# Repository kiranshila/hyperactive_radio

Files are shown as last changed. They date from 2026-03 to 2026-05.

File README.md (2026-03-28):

# Hyperactive//2026 Radio

Experimental real-time, long-range, high-quality, wireless digital audio for Hyperactive 2026.

## Audio quality

| Parameter | Value |
|---|---|
| Codec | Opus (fixed-point) |
| Bitrate | 64 kbps |
| Channels | Stereo |
| Sample rate | 48 kHz |
| Frame size | 20 ms |
| Encoder complexity | 5 / 10 |
| ADC | PCM1808 (24-bit I2S) |

64 kbps stereo Opus at 48 kHz should be transparent for most program material — comparable to a good 128 kbps MP3, but with lower latency and better behaviour at the edges of the bitrate.
The fixed-point build removes float entirely; no performance penalty on Cortex-M33 which has a hardware FPU but where the float Opus path was benchmarked to be slower than fixed-point.

End-to-end latency is approximately one frame (20 ms) of algorithmic delay plus radio airtime (~1.6 ms at 100 kbps for a 160-byte packet) plus any playout buffer on the receiver.

## Radio

| Parameter | Value |
|---|---|
| Radio IC | SX1276 |
| Band | 915 MHz (US ISM) |
| Modulation | GFSK |
| Air rate | 100 kbps |
| TX power | +20 dBm (100 mW) |
| Target range | ~300 m / ~1000 ft mixed indoor/outdoor |
| Link margin | ~18 dB at 100 kbps GFSK |

### Regulatory (FCC Part 15.247)

No frequency hopping required. Part 15.247 has two compliance paths — FHSS is one, but **digital modulation** is the other: fixed frequency, up to +30 dBm EIRP, with two constraints:

- **6 dB bandwidth ≥ 500 kHz** — requires high frequency deviation; at 100 kbps, ±200 kHz deviation gets you there (`BW_6dB ≈ 2 × f_dev + bit_rate`). Lower deviation (e.g. ±50 kHz) only yields ~200 kHz and does not qualify.
- **PSD ≤ 8 dBm in any 3 kHz band** — GFSK spectral peaks at ±f_dev must stay under this limit at the chosen TX power.

The exact deviation and power settings need to be verified against both constraints once the RF configuration is finalised. At +20 dBm with sufficiently high deviation the path is viable, but the numbers need to be checked.

### Packet structure

Each 20 ms Opus frame encodes to roughly 160 bytes at 64 kbps.
With ~10 bytes of framing (sequence number, network ID, CRC) the total packet is ~170 bytes, for an effective air rate of ~68 kbps — well within the 100 kbps channel.

## Performance

MCU runs at **270 MHz** (overclocked from the 150 MHz default; stable at stock 1.1 V).

Benchmarked on hardware against broadband LCG noise (worst case for Opus — no clear pitch, flat spectrum):

| Operation | Cycles (avg) | Time (avg) | Frame budget used |
|---|---|---|---|
| Opus encode, stereo, 64 kbps, 20 ms | 2,299,603 | 8.5 ms | **42.6%** |
| Opus decode, stereo, 64 kbps, 20 ms | 895,420 | 3.3 ms | **16.6%** |

Frame budget = 20 ms = 5,400,000 cycles at 270 MHz.

The encoder leaves 11.5 ms of headroom per frame for I2S DMA and SPI radio management.
The decoder uses only 16.6% of the frame, leaving ample margin for playout buffering and output DMA.

## Firmware architecture

Written in Rust (`no_std`, Embassy async runtime).

```
ha_radio/          # firmware binary (bench + main)
embedded-opus/     # safe Rust wrapper around libopus
opus-sys/          # raw FFI bindings; builds libopus via cc crate
```

`embedded-opus/build.rs` compiles a host-side C probe at build time to determine the exact encoder and decoder state sizes, so buffers are sized precisely without a runtime heap.

### Planned: dual-core pipeline

The encode headroom is comfortable at 270 MHz, but the dual-core split is still planned for clean separation of concerns once the ADC arrives:

- **Core 0** — I2S DMA capture, SX1276 SPI, radio management
- **Core 1** — Opus encode only

A pair of Embassy `Channel` queues (depth 2) connect the cores: PCM frames inbound, encoded packets outbound.

## Build

```sh
cargo build --release --bin ha_radio
cargo build --release --bin bench
```

Requires a Rust nightly toolchain and the `thumbv8m.main-none-eabihf` target (see `rust-toolchain.toml`).

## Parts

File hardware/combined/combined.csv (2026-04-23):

Reference | Qty | Value | MPN | LCSC
A1 | 1 | RaspberryPi_Pico |  | C41407547
C1,C3,C6,C8,C10,C12,C13,C14,C15,C17 | 10 | 10u
C2 | 1 | 22u
C4,C7,C9,C11,C18,C19,C20 | 7 | 100n
C21,C22,C27 | 3 | 1u
C23,C24,C25,C26 | 4 | 220p
FB1,FB6,FB7,FB8,FB9,FB10 | 6 | BLM18PG221SN1 | BLM18PG221SN1 | C80165
J1 | 1 | Barrel_Jack_MountingPin
J2 | 1 | Conn_01x03_Pin
J3,J7 | 2 | Conn_01x02
J4 | 1 | Conn_Coaxial |  | C496550
J8,J9 | 2 | AudioJack3_SwitchT | SJ-3524-SMT-TR | C20182907
Q1 | 1 | DMG2305UX |  | C150470
R1 | 1 | 100k
R2,R3,R4 | 3 | 4.7k
R7 | 1 | 22k
SW1 | 1 | RotaryEncoder_Switch_MP | EC11E18244A5 | C255515
U1 | 1 | LD1117S50TR_SOT223 |  | C347230
U2 | 1 | Ai-Thinker-Ra-01 |  | C503593
U3 | 1 | PCM3060 | PCM3060PWR | C2651841
U4 | 1 | SSD1306
U6 | 1 | PAM8406D | PAM8406DR | C86270
Y1 | 1 | SG-210STF | X1G0041710019 | C255992

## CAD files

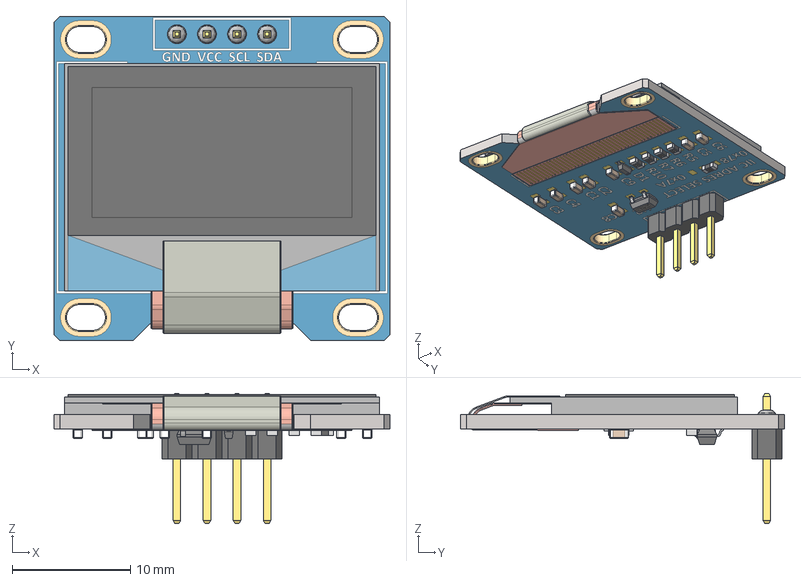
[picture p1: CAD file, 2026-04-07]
hardware/combined/Pantalla OLED 0.96'' 128x64.stp
28.4 x 27.4 x 11.0 mm
SOT-23_TOR
RES_CR16_MTK_1 x 4
RES_CR16_MTK
SOD323F_DIO

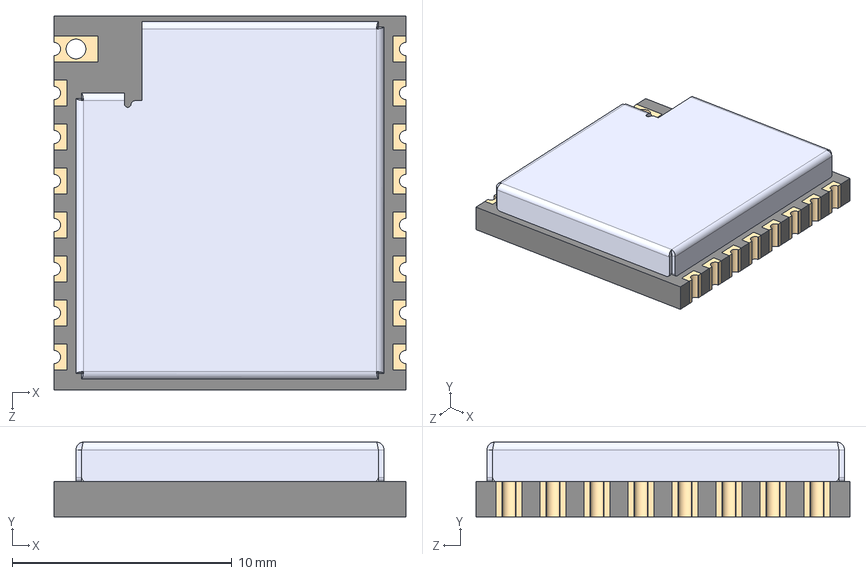
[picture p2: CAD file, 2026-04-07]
hardware/combined/RA-01H--3DModel-STEP-1.STEP
16.0 x 3.40 x 17.0 mm

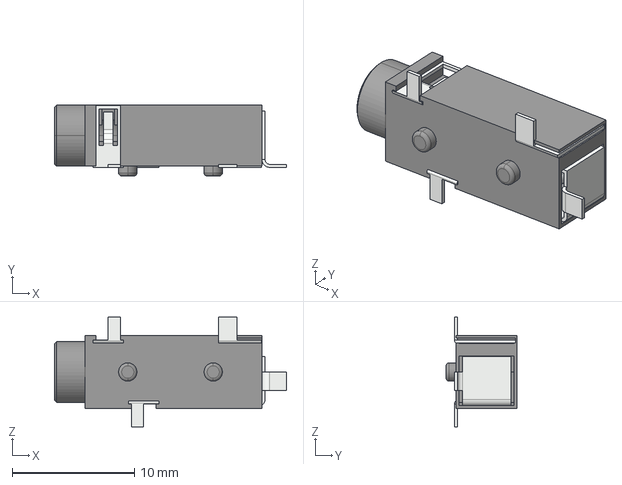
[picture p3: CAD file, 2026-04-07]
hardware/combined/CUI_SJ-3524-SMT-TR.STEP
19.0 x 5.80 x 9.00 mm

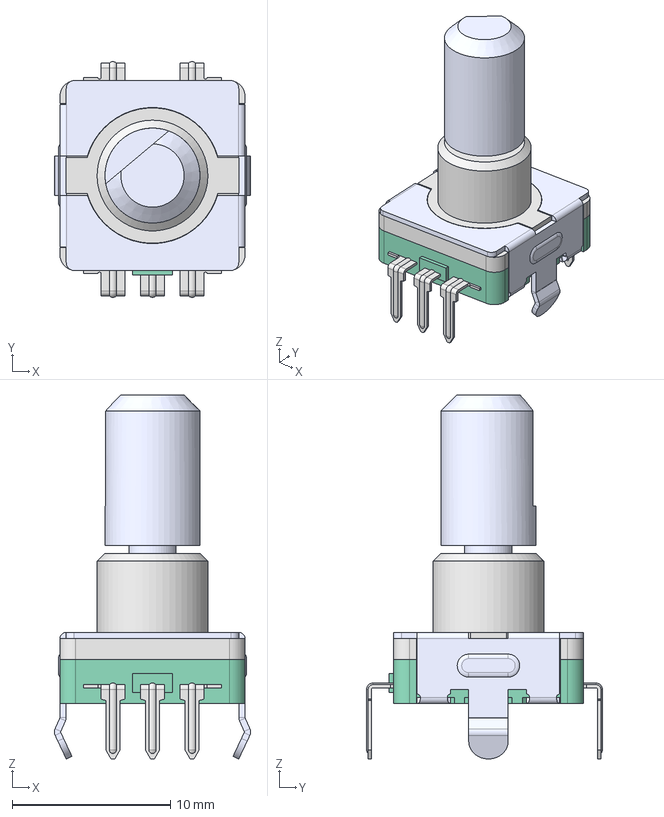
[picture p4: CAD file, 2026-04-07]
hardware/combined/EC11-THT-15F-green.step
12.4 x 14.9 x 23.0 mm
Lb5
15F
EC11-Housing-THT

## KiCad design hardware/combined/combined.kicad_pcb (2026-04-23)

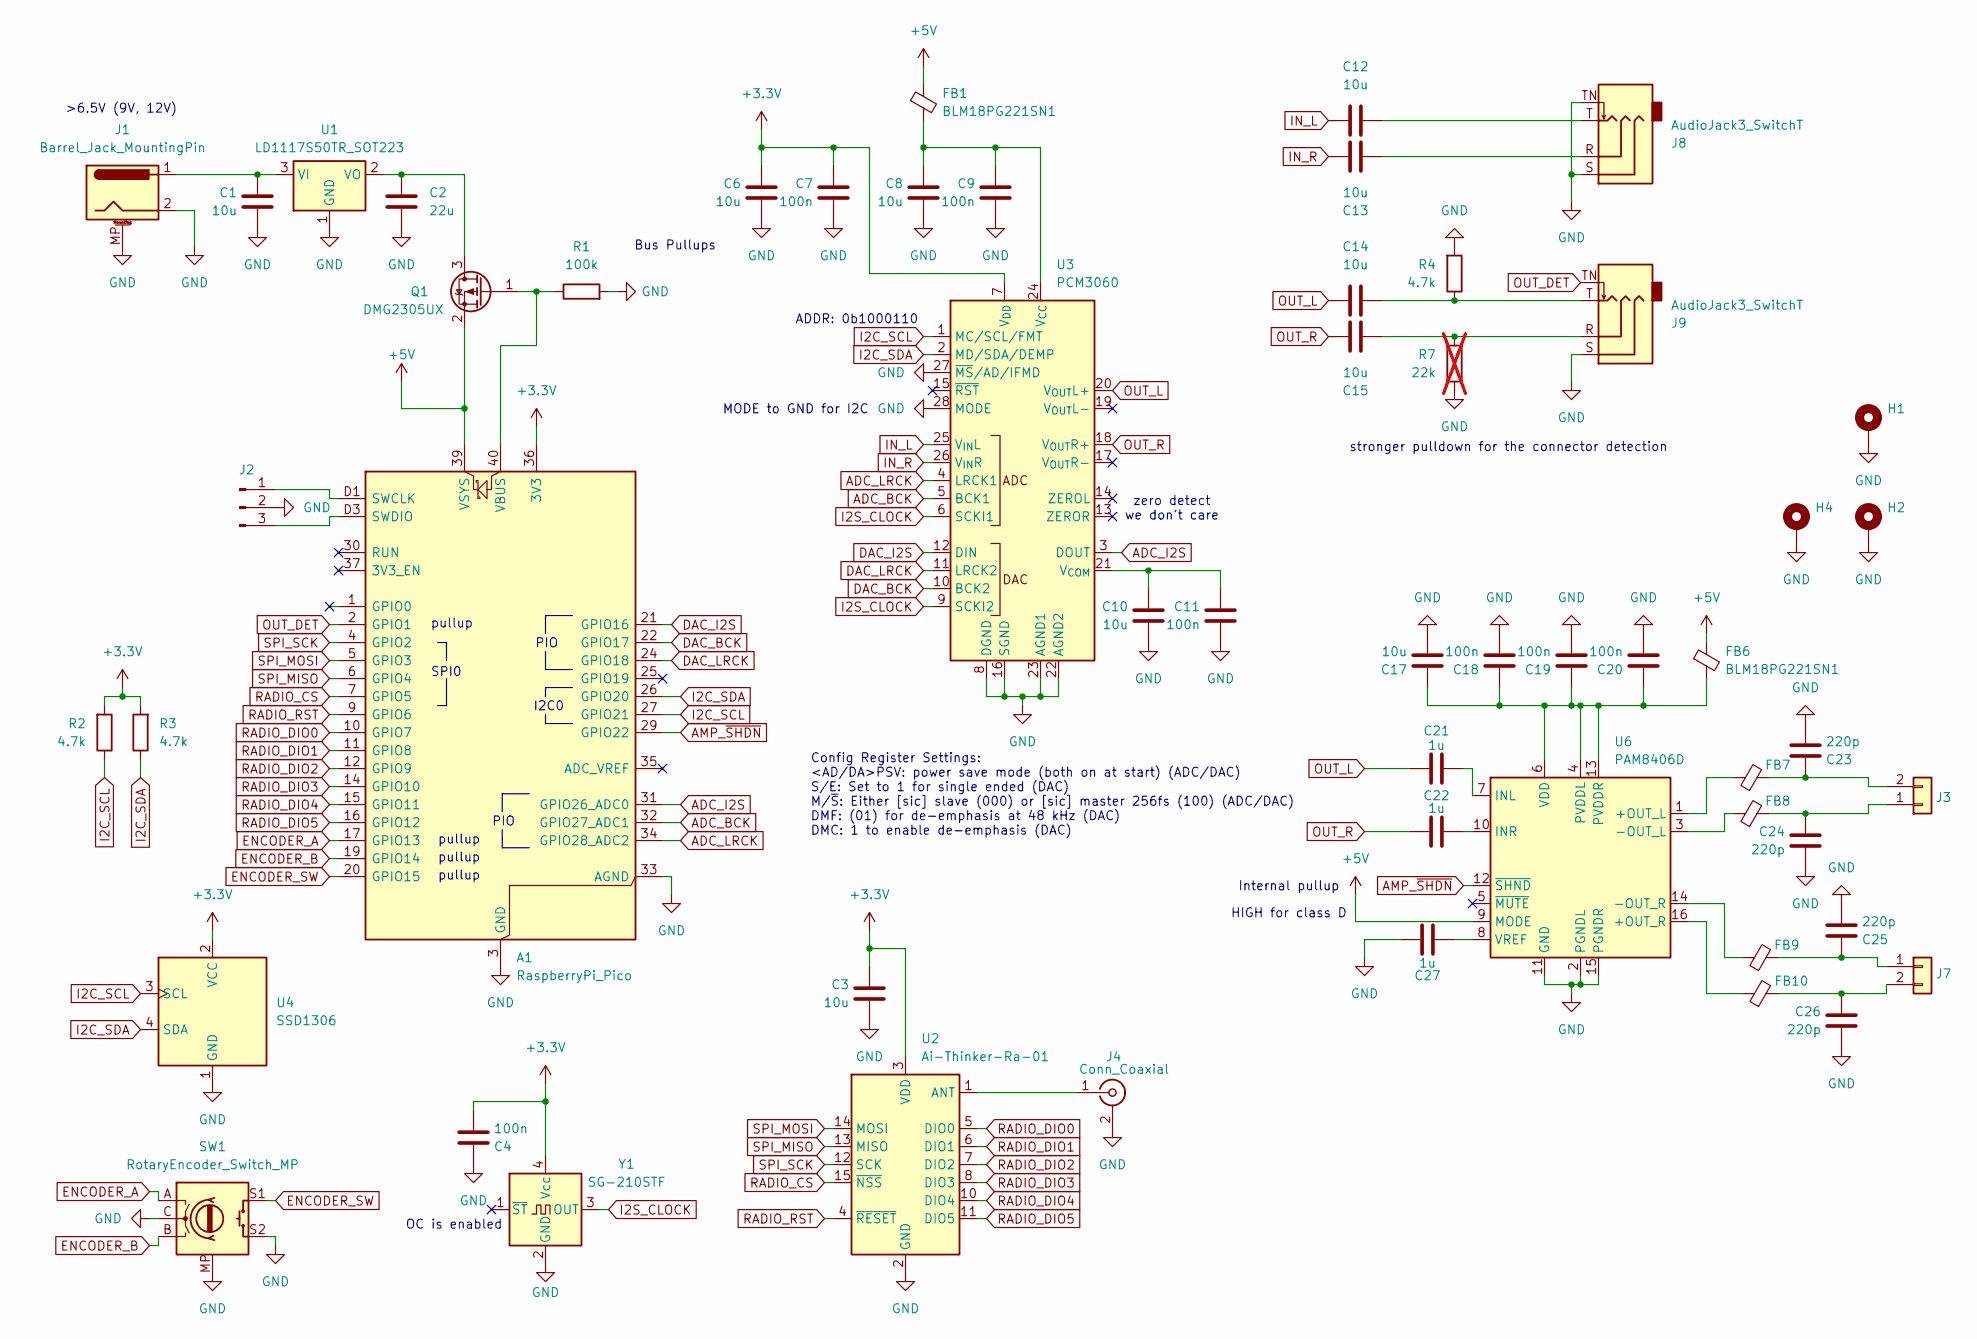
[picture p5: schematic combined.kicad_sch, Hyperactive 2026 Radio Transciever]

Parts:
A1: RaspberryPi_Pico; RaspberryPi_Pico_SMD_HandSolder; LCSC C41407547
C1, C3, C6, C8, C10, C12, C13, C14, C15, C17: 10u; C_0805_2012Metric; MPN CL21A106KOQNNNG
C2: 22u; C_0805_2012Metric; MPN GRM21BR61A226ME51L
C4, C7, C9, C11, C18, C19, C20: 100n; C_0805_2012Metric; MPN 0805ZD104KAT2A
C21, C22, C27: 1u; C_0805_2012Metric; MPN 0805X105K160CT
C23, C24, C25, C26: 220p; C_0603_1608Metric; MPN C0603C221J1HACAUTO
FB1, FB6, FB7, FB8, FB9, FB10: BLM18PG221SN1; L_0603_1608Metric; MPN BLM18PG221SN1; LCSC C80165
H1, H2, H4: MountingHole_Pad; MountingHole_3.2mm_M3_DIN965_Pad_TopBottom
J1: Barrel_Jack_MountingPin; BarrelJack_Horizontal
J2: Conn_01x03_Pin; PinHeader_1x03_P2.54mm_Vertical
J3, J7: Conn_01x02; PinHeader_1x02_P2.54mm_Vertical
J4: Conn_Coaxial; SMA_Samtec_SMA-J-P-H-ST-EM1_EdgeMount; LCSC C496550
J8, J9: AudioJack3_SwitchT; Jack_3.5mm_CUI_SJ-3524-SMT_Horizontal; MPN SJ-3524-SMT-TR; LCSC C20182907
Q1: DMG2305UX; SOT-23; LCSC C150470
R1: 100k; R_0805_2012Metric; MPN RG2012P-104-B-T5
R2, R3, R4: 4.7k; R_0805_2012Metric; MPN RG2012P-472-D-T5
R7: 22k; R_0805_2012Metric; MPN RG2012P-223-B-T5; not fitted
SW1: RotaryEncoder_Switch_MP; RotaryEncoder_Alps_EC11E-Switch_Vertical_H20mm; MPN EC11E09244BS; LCSC C470742
U1: LD1117S50TR_SOT223; SOT-223-3_TabPin2; LCSC C347230
U2: Ai-Thinker-Ra-01; Ai-Thinker-Ra-01-LoRa; LCSC C503593
U3: PCM3060; TSSOP-28_4.4x9.7mm_P0.65mm; MPN PCM3060PWR; LCSC C2651841
U4: SSD1306; SSD1306_0.96_Oled
U6: PAM8406D; SOIC-16_3.9x9.9mm_P1.27mm; MPN PAM8406DR; LCSC C86270
Y1: SG-210STF; Oscillator_SMD_SeikoEpson_SG210-4Pin_2.5x2.0mm; MPN X1G0041710019; LCSC C255992

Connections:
+3.3V: A1.36 (3V3), C3.2, C4.1, C6.2, C7.2, R2.2, R3.2, U2.3 (VDD), U3.7 (V_{DD}), U4.2 (VCC), Y1.4 (Vcc)
+5V: A1.39 (VSYS), FB1.1, FB6.1, Q1.2 (S), U6.9 (MODE)
ADC_BCK: A1.32 (GPIO27_ADC1), U3.5 (BCK1)
ADC_I2S: A1.31 (GPIO26_ADC0), U3.3 (DOUT)
ADC_LRCK: A1.34 (GPIO28_ADC2), U3.4 (LRCK1)
AMP_~SHDN: A1.29 (GPIO22), U6.12 (~SHND)
DAC_BCK: A1.22 (GPIO17), U3.10 (BCK2)
DAC_I2S: A1.21 (GPIO16), U3.12 (DIN)
DAC_LRCK: A1.24 (GPIO18), U3.11 (LRCK2)
ENCODER_A: A1.17 (GPIO13), SW1.A
ENCODER_B: A1.19 (GPIO14), SW1.B
ENCODER_SW: A1.20 (GPIO15), SW1.S1
GND: A1.3 (GND), A1.8 (GND), A1.13 (GND), A1.18 (GND), A1.23 (GND), A1.28 (GND), A1.33 (AGND), A1.38 (GND), A1.D2 (GND), C1.1, C2.2, C3.1, C4.2, C6.1, C7.1, C8.1, C9.1, C10.1, C11.1, C17.1, C18.1, C19.1, C20.1, C23.1, C24.1, C25.1, C26.1, C27.2, H1.1 (1_1), H2.1 (1_1), H4.1 (1_1), J1.2, J1.MP (MountPin), J2.2, J4.2 (Ext), J8.S, J8.TN, J9.S, R1.2, R4.2, R7.1, SW1.C, SW1.MP, SW1.S2, U1.1 (GND), U2.2 (GND), U2.9 (GND), U2.16 (GND), U3.8 (DGND), U3.16 (SGND), U3.22 (AGND2), U3.23 (AGND1), U3.27 (~MS/AD/IFMD), U3.28 (MODE), U4.1 (GND), U6.2 (PGNDL), U6.11 (GND), U6.15 (PGNDR), Y1.2 (GND)
I2C_SCL: A1.27 (GPIO21), R2.1, U3.1 (MC/SCL/FMT), U4.3 (SCL)
I2C_SDA: A1.26 (GPIO20), R3.1, U3.2 (MD/SDA/DEMP), U4.4 (SDA)
I2S_CLOCK: U3.6 (SCKI1), U3.9 (SCKI2), Y1.3 (OUT)
IN_L: C12.1, U3.25 (V_{IN}L)
IN_R: C13.1, U3.26 (V_{IN}R)
unnamed: A1.D1 (SWCLK), J2.1
unnamed: A1.D3 (SWDIO), J2.3
unnamed: A1.40 (VBUS), Q1.1 (G), R1.1
unnamed: C12.2, J8.T
unnamed: C13.2, J8.R
unnamed: C14.2, J9.T, R4.1
unnamed: C15.2, J9.R, R7.2
unnamed: C24.2, FB8.2, J3.1
unnamed: C23.2, FB7.2, J3.2
unnamed: J4.1 (In), U2.1 (ANT)
unnamed: C25.2, FB9.2, J7.1
unnamed: C26.2, FB10.2, J7.2
unnamed: C2.1, Q1.3 (D), U1.2 (VO)
unnamed: C1.2, J1.1, U1.3 (VI)
unnamed: C8.2, C9.2, FB1.2, U3.24 (V_{CC})
unnamed: C10.2, C11.2, U3.21 (V_{COM})
unnamed: FB7.1, U6.1 (+OUT_L)
unnamed: FB10.1, U6.16 (+OUT_R)
unnamed: FB8.1, U6.3 (-OUT_L)
unnamed: FB9.1, U6.14 (-OUT_R)
unnamed: C21.1, U6.7 (INL)
unnamed: C22.1, U6.10 (INR)
unnamed: C17.2, C18.2, C19.2, C20.2, FB6.2, U6.4 (PVDDL), U6.6 (VDD), U6.13 (PVDDR)
unnamed: C27.1, U6.8 (VREF)
OUT_DET: A1.2 (GPIO1), J9.TN
OUT_L: C14.1, C21.2, U3.20 (V_{OUT}L+)
OUT_R: C15.1, C22.2, U3.18 (V_{OUT}R+)
RADIO_CS: A1.7 (GPIO5), U2.15 (~NSS)
RADIO_DIO0: A1.10 (GPIO7), U2.5 (DIO0)
RADIO_DIO1: A1.11 (GPIO8), U2.6 (DIO1)
RADIO_DIO2: A1.12 (GPIO9), U2.7 (DIO2)
RADIO_DIO3: A1.14 (GPIO10), U2.8 (DIO3)
RADIO_DIO4: A1.15 (GPIO11), U2.10 (DIO4)
RADIO_DIO5: A1.16 (GPIO12), U2.11 (DIO5)
RADIO_RST: A1.9 (GPIO6), U2.4 (~RESET)
SPI_MISO: A1.6 (GPIO4), U2.13 (MISO)
SPI_MOSI: A1.5 (GPIO3), U2.14 (MOSI)
SPI_SCK: A1.4 (GPIO2), U2.12 (SCK)

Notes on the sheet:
MODE to GND for I2C
I2C0
stronger pulldown for the connector detection
HIGH for class D
PIO
Internal pullup
OC is enabled
pullup
Bus Pullups
ADDR: 0b1000110
zero detect we don't care
>6.5V (9V, 12V)
Config Register Settings: <AD/DA>PSV: power save mode (both on at start) (ADC/DAC) S/E: Set to 1 for single ended (DAC) M/~{S}: Either [sic] slave (000) or [sic] master 256fs (100) (ADC/DAC) DMF: (01) for de-emphasis at 48 kHz (DAC) DMC: 1 to enable de-emphasis (DAC)
SPI0

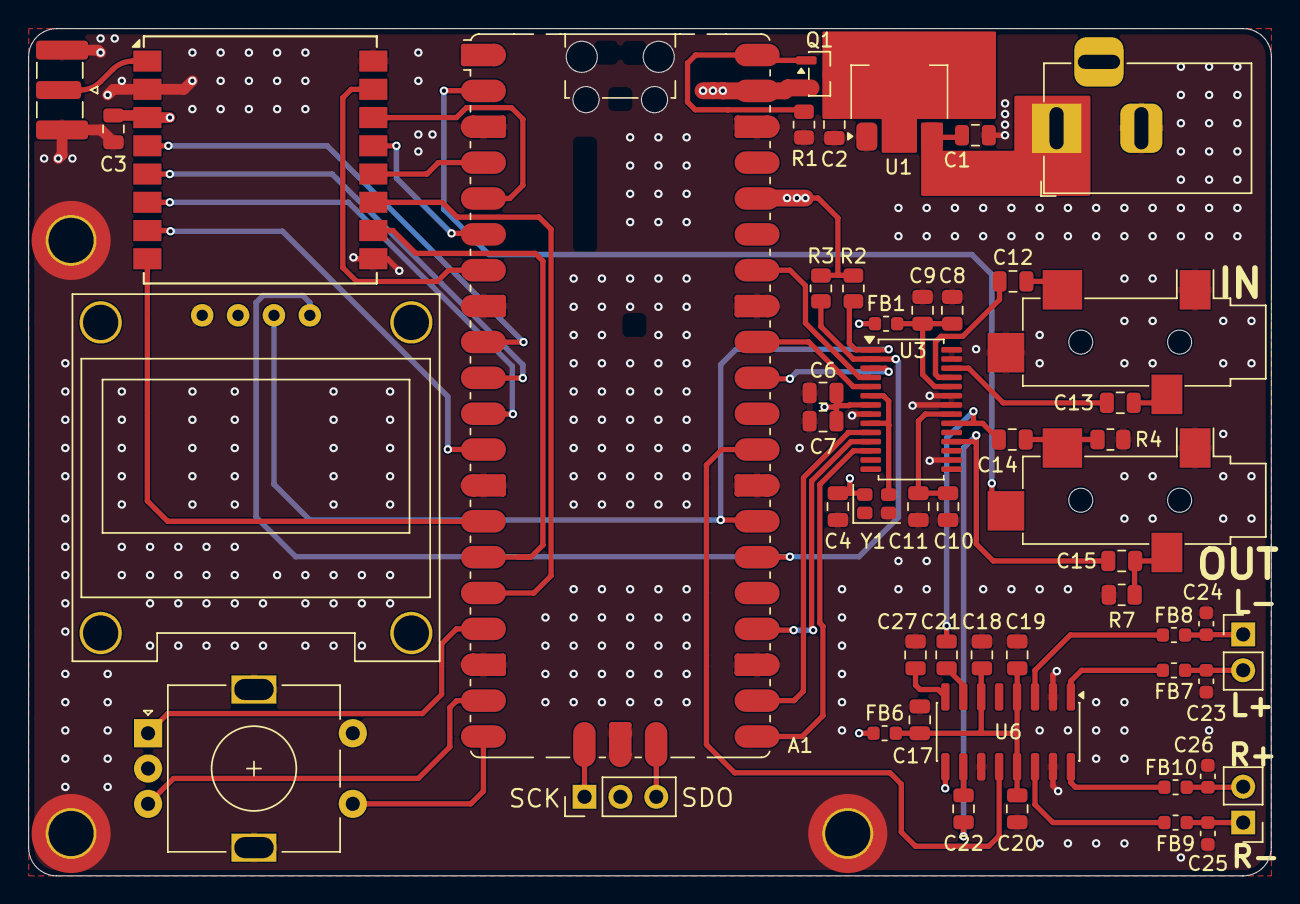
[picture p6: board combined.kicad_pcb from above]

Board: 4 copper layers, 88.0 x 60.0 mm, 55 parts (0 on the bottom side), 56 nets.

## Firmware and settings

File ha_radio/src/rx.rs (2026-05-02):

#![no_std]
#![no_main]
#![feature(impl_trait_in_assoc_type)]

use {
    board_support::{
        Board, I2sOutputPio, Pcm3060Board, Sx127xBoard, VolumeEncoderPio,
        consts::{
            FRAME_SAMPLES, OPUS_BUF_SIZE, OpusPacket, PackedAudioFrame, RADIO_BITRATE_BPS,
            RADIO_FREQ_HZ, RADIO_SYNC_WORD, SAMPLE_RATE,
        },
    },
    core::ptr::addr_of_mut,
    defmt::*,
    defmt_rtt as _,
    embassy_executor::Executor,
    embassy_futures::join::join,
    embassy_rp::{
        bind_interrupts,
        config::Config as SystemConfig,
        dma::InterruptHandler as DmaInterruptHandler,
        gpio::{Input, Output},
        i2c::InterruptHandler as I2cInterruptHandler,
        multicore::{Stack, spawn_core1},
        peripherals::{DMA_CH0, DMA_CH1, DMA_CH2, DMA_CH3, I2C0, PIO0, PIO1},
        pio::InterruptHandler as PioInterruptHandler,
        pwm::{Pwm, SetDutyCycle},
    },
    embassy_sync::{
        blocking_mutex::raw::CriticalSectionRawMutex,
        zerocopy_channel::{Channel, Receiver, Sender},
    },
    embassy_time::Timer,
    embedded_opus::DECODER_STATE_SIZE_STEREO,
    panic_probe as _,
    static_cell::StaticCell,
    sx127x::GfskRxConfig,
};

bind_interrupts!(struct Irqs {
    DMA_IRQ_0 => DmaInterruptHandler<DMA_CH0>, DmaInterruptHandler<DMA_CH1>, DmaInterruptHandler<DMA_CH2>, DmaInterruptHandler<DMA_CH3>;
    PIO0_IRQ_0 => PioInterruptHandler<PIO0>;
    PIO1_IRQ_0 => PioInterruptHandler<PIO1>;
    I2C0_IRQ => I2cInterruptHandler<I2C0>;
});

static mut CORE1_STACK: Stack<262144> = Stack::new();
static EXECUTOR0: StaticCell<Executor> = StaticCell::new();
static EXECUTOR1: StaticCell<Executor> = StaticCell::new();

type PackedAudioFrameChannel = Channel<'static, CriticalSectionRawMutex, PackedAudioFrame>;
type PackedAudioFrameSender = Sender<'static, CriticalSectionRawMutex, PackedAudioFrame>;
type PackedAudioFrameReceiver = Receiver<'static, CriticalSectionRawMutex, PackedAudioFrame>;

type OpusPacketChannel = Channel<'static, CriticalSectionRawMutex, OpusPacket>;
type OpusPacketSender = Sender<'static, CriticalSectionRawMutex, OpusPacket>;
type OpusPacketReceiver = Receiver<'static, CriticalSectionRawMutex, OpusPacket>;

#[embassy_executor::task]
async fn amp_enable(out_det: Input<'static>, mut amp_nshdn: Output<'static>) {
    info!("monitoring audio out jack");
    let mut enabled = false;
    loop {
        if out_det.is_low() && !enabled {
            info!("Enabling amplifier");
            enabled = true;
            amp_nshdn.set_high();
        } else if out_det.is_high() && enabled {
            info!("Disabling amplifier");
            enabled = false;
            amp_nshdn.set_low();
        }
        Timer::after_millis(100).await;
    }
}

/// Radio RX — Core 0.  Receives GFSK packets and forwards to the decoder.
/// DIO0 is mapped to PayloadReady in FSK packet mode.
#[embassy_executor::task]
async fn radio_rx_task(
    mut tx: OpusPacketSender,
    mut radio: Sx127xBoard,
    mut dio0: Input<'static>,
    mut rst: Output<'static>,
) {
    // Hardware reset: low ≥100µs, then wait ≥5ms for oscillator startup.
    rst.set_low();
    Timer::after_millis(1).await;
    rst.set_high();
    Timer::after_millis(10).await;

    loop {
        let version = radio.read_version().await.unwrap();
        info!("radio: version=0x{:02x} (expect 0x12)", version);

        let gfsk_cfg = GfskRxConfig {
            frequency_hz: RADIO_FREQ_HZ,
            bitrate_bps: RADIO_BITRATE_BPS,
            sync_word: RADIO_SYNC_WORD,
            max_payload_len: OPUS_BUF_SIZE as u8,
        };
        radio.configure_gfsk_rx(&gfsk_cfg).await.unwrap();
        info!("radio: configured for rx");

        let mut pkt_buf = [0u8; 255];
        let mut timeouts = 0;
        'rx: loop {
            match radio.receive(&mut dio0, &mut pkt_buf).await {
                Ok(len) => {
                    timeouts = 0;
                    if len > OPUS_BUF_SIZE {
                        warn!("radio: pkt too large {}", len);
                        let mut opus = tx.send().await;
                        opus.len = 0;
                        opus.send_done();
                        continue;
                    }
                    // info!("rx: len={}", len);
                    // info!("rx: rssi={}dBm", radio.read_rssi_dbm().await.unwrap_or(0));
                    let mut opus = tx.send().await;
                    opus.data[..len].copy_from_slice(&pkt_buf[..len]);
                    opus.len = len;
                    opus.send_done();
                }
                Err(sx127x::Error::Timeout) => {
                    let rssi = radio.read_rssi_dbm().await.unwrap_or(0);

                    timeouts += 1;
                    info!("radio: rx timeout #{} rssi={}dBm", timeouts, rssi);
                    if timeouts > 10 {
                        break 'rx;
                    }
                }
                Err(sx127x::Error::CrcError) => {
                    warn!("radio: rx CRC error");
                    // send an empty packet to trigger PLC
                    let mut opus = tx.send().await;
                    opus.len = 0;
                    opus.send_done();
                }
                Err(e) => {
                    warn!("radio: rx err {}", defmt::Debug2Format(&e));
                }
            }
        }
    }
}

/// Opus decoder — Core 1.  CPU-bound, runs on its own executor so it
/// never starves the I2S output DMA on Core 0.
#[embassy_executor::task]
async fn opus_decode_task(mut rx: OpusPacketReceiver, mut tx: PackedAudioFrameSender) {
    let mut state_buf = [0u8; DECODER_STATE_SIZE_STEREO];
    let mut decoder = embedded_opus::Decoder::new(&mut state_buf, SAMPLE_RATE as i32, 2).unwrap();
    info!("decode: starting");
    loop {
        let (opus, mut pcm_slot) = join(rx.receive(), tx.send()).await;
        let pcm: &mut [i16] = bytemuck::cast_slice_mut(&mut (*pcm_slot));
        match decoder.decode(&opus.data[0..opus.len], pcm, false) {
            Ok(_len) => {}
            Err(e) => {
                error!(
                    "decode: failed ({})",
                    match e {
                        embedded_opus::Error::BadArg => "bad argument",
                        embedded_opus::Error::BufferTooSmall => "buffer too small",
                        embedded_opus::Error::InternalError => "internal error",
                        embedded_opus::Error::InvalidPacket => "invalid packet",
                        embedded_opus::Error::Unimplemented => "unimplemented (?)",
                        embedded_opus::Error::InvalidState => "invalid state",
                        embedded_opus::Error::AllocFail => "allocation failure",
                        _ => "!?",
                    }
                );
                if let Err(_) = decoder.plc(pcm) {
                    error!("decode: loss concealment failed");
                }
            }
        }
        opus.receive_done();
        pcm_slot.send_done();
    }
}

/// I2S TX output — Core 0.  Plays decoded PCM on the PCM5102A DAC.
#[embassy_executor::task]
async fn i2s_out_task(
    mut i2s: I2sOutputPio,
    mut rx: PackedAudioFrameReceiver,
    mut led_1: Pwm<'static>,
    mut led_2: Pwm<'static>,
) {
    i2s.start();
    info!("i2s out: started");
    loop {
        let buf = rx.receive().await;
        // Copy the first sample for LED metering before starting DMA
        let sample = buf[0];
        i2s.write(&*buf).await;
        buf.receive_done();

        let r_level = (((sample >> 16) as i16).saturating_abs() / (i16::MAX / 100)) as u8;
        let l_level = ((sample as i16).saturating_abs() / (i16::MAX / 100)) as u8;
        led_1.set_duty_cycle_percent(r_level).unwrap();
        led_2.set_duty_cycle_percent(l_level).unwrap();
    }
}

/// Codec control task -- currently just sets the volume
#[embassy_executor::task]
async fn codec_control_task(mut codec: Pcm3060Board, mut volume_knob: VolumeEncoderPio) {
    codec.reset().await.unwrap();
    codec.dac_init().await.unwrap();
    info!("codec configured");

    loop {
        volume_knob.poll().await;
        let vol = volume_knob.pos();

        // mute if volume is sufficiently low
        let vol = if vol == volume_knob.min() { 0 } else { vol };

        // NOTE: fine because of the type constraints
        if let Err(_) = codec.set_volume(vol as u8).await {
            error!("codec control: error setting volume");
        }
    }
}

#[cortex_m_rt::entry]
fn main() -> ! {
    // Setup the board
    let mut board = Board::new(SystemConfig::default(), Irqs);

    // Turn off LEDs initially
    board.led_1.set_duty_cycle_percent(0).unwrap();
    board.led_2.set_duty_cycle_percent(0).unwrap();

    // ----- Set up the two zerocopy channels

    // Radio -> Opus decode (depth 3: absorbs radio RX jitter / SPI stalls)
    static RADIO_OPUS_BUF: StaticCell<[OpusPacket; 3]> = StaticCell::new();
    let radio_opus_buf = RADIO_OPUS_BUF.init(
        [OpusPacket {
            data: [0; OPUS_BUF_SIZE],
            len: 0,
        }; 3],
    );
    static RADIO_OPUS_CHAN: StaticCell<OpusPacketChannel> = StaticCell::new();
    let radio_opus_chan = RADIO_OPUS_CHAN.init(Channel::new(radio_opus_buf));
    let (radio_opus_tx, radio_opus_rx) = radio_opus_chan.split();

    // Opus decode -> I2S output (depth 3: absorbs decode time variance)
    static OPUS_I2S_BUF: StaticCell<[PackedAudioFrame; 3]> = StaticCell::new();
    let opus_i2s_buf = OPUS_I2S_BUF.init([[0; FRAME_SAMPLES / 2]; 3]);
    static OPUS_I2S_CHAN: StaticCell<PackedAudioFrameChannel> = StaticCell::new();
    let opus_i2s_chan = OPUS_I2S_CHAN.init(Channel::new(opus_i2s_buf));
    let (opus_i2s_tx, opus_i2s_rx) = opus_i2s_chan.split();

    // ----- Core 1: Opus decoding (pure CPU, no DMA needed)
    spawn_core1(
        board.core_1,
        unsafe { &mut *addr_of_mut!(CORE1_STACK) },
        move || {
            let executor1 = EXECUTOR1.init(Executor::new());
            executor1.run(|spawner| {
                spawner.spawn(opus_decode_task(radio_opus_rx, opus_i2s_tx).unwrap());
            });
        },
    );

    // ----- Core 0: radio RX + I2S TX output (all DMA lives here)
    let executor0 = EXECUTOR0.init(Executor::new());
    executor0.run(|spawner| {
        spawner.spawn(codec_control_task(board.codec, board.volume_knob).unwrap());
        spawner.spawn(
            radio_rx_task(radio_opus_tx, board.radio, board.radio_d0, board.radio_rst).unwrap(),
        );
        spawner.spawn(i2s_out_task(board.i2s_out, opus_i2s_rx, board.led_1, board.led_2).unwrap());
        spawner.spawn(amp_enable(board.out_det, board.amp_nshdn).unwrap());
    })
}

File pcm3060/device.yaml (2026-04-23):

config:
    register_address_type: u8
    defmt_feature: defmt

Reg64:
    type: register
    size_bits: 8
    address: 64
    fields:
        mrst:
            base: bool
            start: 7
            description: Mode control register reset
        srst:
            base: bool
            start: 6
            description: System reset
        adpsv:
            base: bool
            start: 5
            description: ADC power-save control
        dapsv:
            base: bool
            start: 4
            description: DAC power-save control
        s_e:
            base: bool
            start: 0
            description: VOUT configuration control

Reg65:
    type: register
    size_bits: 8
    address: 65
    description: AT21, digital attenuation setting for VOUT_L
    fields:
        value:
            base: uint
            start: 0
            end: 8

Reg66:
    type: register
    size_bits: 8
    address: 66
    description: AT22, digital attenuation setting for VOUT_R
    fields:
        value:
            base: uint
            start: 0
            end: 8

Reg67:
    type: register
    size_bits: 8
    address: 67
    fields:
        csel:
            base: bool
            start: 7
            description: Clock select for DAC operation
        m_ns:
            base: uint
            start: 4
            end: 7
            description: Audio interface mode for DAC
            conversion:
                name: DacMode
                Slave: 0
                Master768Fs: 1
                Master512Fs: 2
                Master384Fs: 3
                Master256Fs: 4
                Master192Fs: 5
                Master128Fs: 6
                Reserved: catch_all
        fmt:
            base: uint
            start: 0
            end: 2
            description: Interface format for DAC
            conversion: "crate::Format"

Reg68:
    type: register
    size_bits: 8
    address: 68
    fields:
        over:
            base: bool
            start: 6
            description: Oversampling rate control
        drev:
            base: bool
            start: 2
            description: Output phase select
        mute_r:
            base: bool
            start: 1
        mute_l:
            base: bool
            start: 0

Reg69:
    type: register
    size_bits: 8
    address: 69
    fields:
        flt:
            base: bool
            start: 7
            description: Digital filter rolloff control
        dmf:
            base: uint
            start: 5
            end: 7
            conversion:
                name: DeEmphasisRate
                Rate441kHz: 0
                Rate48kHz: 1
                Rate32kHz: 2
                Reserved: catch_all
        dmc:
            base: bool
            start: 4
            description: Digital de-emphasis control
        zrev:
            base: bool
            start: 1
            description: Zero-Flag polarity select
        azro:
            base: bool
            start: 0
            description: Zero-Flag function select

Reg70:
    type: register
    size_bits: 8
    address: 70
    description: Digital attenuation level setting L-ch part of DOUT
    fields:
        value:
            base: uint
            start: 0
            end: 8

Reg71:
    type: register
    size_bits: 8
    address: 71
    description: Digital attenuation level setting R-ch part of DOUT
    fields:
        value:
            base: uint
            start: 0
            end: 8

Reg72:
    type: register
    size_bits: 8
    address: 72
    fields:
        csel:
            base: bool
            start: 7
            description: Clock select for ADC operation
        m_ns:
            base: uint
            start: 4
            end: 7
            description: Audio interface mode for ADC
            conversion:
                name: AdcMode
                Slave: 0
                Master768Fs: 1
                Master512Fs: 2
                Master384Fs: 3
                Master256Fs: 4
                Reserved: catch_all
        fmt:
            base: uint
            start: 0
            end: 2
            description: Audio interface format for ADC
            conversion: "crate::Format"

Reg73:
    type: register
    size_bits: 8
    address: 73
    fields:
        zcdd:
            base: bool
            start: 4
            description: Zero-Cross detection disable for digital attenuation
        byp:
            base: bool
            start: 3
            description: HPF bypass control
        drev:
            base: bool
            start: 2
            description: Input phase select
        mute_r:
            base: bool
            start: 1
        mute_l:
            base: bool
            start: 0

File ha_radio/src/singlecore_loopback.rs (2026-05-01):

#![no_std]
#![no_main]
#![feature(impl_trait_in_assoc_type)]

use {
    board_support::{
        Board, I2sInputPio, I2sOutputPio, Pcm3060Board, VolumeEncoderPio,
        consts::{FRAME_SAMPLES, OPUS_BUF_SIZE, OpusPacket, PackedAudioFrame, SAMPLE_RATE},
    },
    defmt::*,
    defmt_rtt as _,
    embassy_executor::Spawner,
    embassy_futures::join::join,
    embassy_rp::{
        bind_interrupts,
        config::Config as SystemConfig,
        dma::InterruptHandler as DmaInterruptHandler,
        i2c::InterruptHandler as I2cInterruptHandler,
        peripherals::{DMA_CH0, DMA_CH1, DMA_CH2, DMA_CH3, I2C0, PIO0, PIO1},
        pio::InterruptHandler as PioInterruptHandler,
    },
    embassy_sync::{
        blocking_mutex::raw::CriticalSectionRawMutex,
        zerocopy_channel::{Channel, Receiver, Sender},
    },
    embassy_time::Timer,
    embedded_opus::{
        Application, DECODER_STATE_SIZE_STEREO, Decoder, ENCODER_STATE_SIZE_STEREO, Encoder,
    },
    panic_probe as _,
    static_cell::StaticCell,
};

bind_interrupts!(struct Irqs {
    DMA_IRQ_0 => DmaInterruptHandler<DMA_CH0>, DmaInterruptHandler<DMA_CH1>, DmaInterruptHandler<DMA_CH2>, DmaInterruptHandler<DMA_CH3>;
    PIO0_IRQ_0 => PioInterruptHandler<PIO0>;
    PIO1_IRQ_0 => PioInterruptHandler<PIO1>;
    I2C0_IRQ => I2cInterruptHandler<I2C0>;
});

// ----- TASKS
// Four-stage pipeline:
// Task 1: Capture I2S from PCM1808
// Task 2: Encode with Opus (This will block for ~18 ms)
// Task 3: Decode with Opus (This will block for ~5 ms)
// Task 4: Transmit I2S to PCM1502A
//
// Channels connect the four tasks

type PackedAudioFrameChannel = Channel<'static, CriticalSectionRawMutex, PackedAudioFrame>;
type PackedAudioFrameSender = Sender<'static, CriticalSectionRawMutex, PackedAudioFrame>;
type PackedAudioFrameReceiver = Receiver<'static, CriticalSectionRawMutex, PackedAudioFrame>;

type OpusPacketChannel = Channel<'static, CriticalSectionRawMutex, OpusPacket>;
type OpusPacketSender = Sender<'static, CriticalSectionRawMutex, OpusPacket>;
type OpusPacketReceiver = Receiver<'static, CriticalSectionRawMutex, OpusPacket>;

#[embassy_executor::task]
async fn i2s_in_task(mut i2s: I2sInputPio, mut tx: PackedAudioFrameSender) {
    // Start the I2S input
    i2s.start();
    info!("i2s in: started");
    loop {
        // Grab the next buffer from the channel.
        // If this blocks, the pipeline is behind and the PIO FIFO
        // will overflow (only 166µs of headroom at 48kHz with 8-deep FIFO).
        let t = embassy_time::Instant::now();
        let mut buf = tx.send().await;
        let wait_us = t.elapsed().as_micros();
        if wait_us > 100 {
            warn!("i2s in: stalled {}us waiting for free buffer", wait_us);
        }
        // Start the DMA transfer directly into the buffer
        i2s.read(&mut *buf).await;
        // Notify the channel this buffer has good data in it
        buf.send_done();
    }
}

#[embassy_executor::task]
async fn opus_encode_task(mut rx: PackedAudioFrameReceiver, mut tx: OpusPacketSender) {
    let mut state_buf = [0u8; ENCODER_STATE_SIZE_STEREO];
    let mut encoder =
        Encoder::new(&mut state_buf, SAMPLE_RATE as i32, 2, Application::Audio).unwrap();
    encoder.set_bitrate(64_000).unwrap(); // 64kbps
    encoder.set_complexity(5).unwrap(); // Middle of the road, benched ok
    info!("encode: starting");
    loop {
        // Acquire both slots concurrently to avoid holding the PCM buffer
        // while waiting for a free packet slot
        let (pcm, mut opus) = join(rx.receive(), tx.send()).await;
        // bytemuck reinterprets [u32] as [i16] in-place (zero-copy).
        // Little-endian: each u32 (left<<16)|right becomes [right, left] as i16.
        // Sample VALUES are correct native-endian signed integers.
        // Channel order is [R, L, R, L, ...] — swapped, but Opus takes
        // native-endian i16 (not big-endian), so values are correct.
        // The decode side uses the same layout, making the round-trip consistent.
        let pcm_raw: &[i16] = bytemuck::cast_slice(pcm.as_slice());
        // Encode into the packet buffer (sized to the radio payload limit).
        match encoder.encode(pcm_raw, &mut opus.data) {
            Ok(len) => opus.len = len,
            Err(_e) => {
                error!("encode: failed");
                opus.len = 0;
            }
        }
        // Release PCM buffer first so I2S DMA can reclaim it
        pcm.receive_done();
        opus.send_done();
    }
}

/// Opus decoder — Core 1.  CPU-bound, runs on its own executor so it
/// never starves the I2S output DMA on Core 0.
#[embassy_executor::task]
async fn opus_decode_task(mut rx: OpusPacketReceiver, mut tx: PackedAudioFrameSender) {
    let mut state_buf = [0u8; DECODER_STATE_SIZE_STEREO];
    let mut decoder = Decoder::new(&mut state_buf, SAMPLE_RATE as i32, 2).unwrap();
    info!("decode: starting");
    loop {
        let (opus, mut pcm_slot) = join(rx.receive(), tx.send()).await;
        let pcm: &mut [i16] = bytemuck::cast_slice_mut(&mut (*pcm_slot));
        match decoder.decode(&opus.data[0..opus.len], pcm, false) {
            Ok(_len) => {}
            Err(_e) => {
                error!("decode: failed");
                decoder.plc(pcm).ok();
            }
        }
        opus.receive_done();
        pcm_slot.send_done();
    }
}

#[embassy_executor::task]
async fn i2s_out_task(mut i2s: I2sOutputPio, mut rx: PackedAudioFrameReceiver) {
    // Double-buffer: pre-fetch next frame during DMA playback so the
    // gap between DMA transfers is just a function call, not a channel wait.
    let mut buf_a = [0u32; FRAME_SAMPLES / 2];
    let mut buf_b = [0u32; FRAME_SAMPLES / 2];

    // Prime: fill first buffer before starting playback (avoids startup clicks)
    let slot = rx.receive().await;
    buf_a.copy_from_slice(&*slot);
    slot.receive_done();

    i2s.start();
    info!("i2s out: started");

    loop {
        // Play buf_a, pre-fetch into buf_b
        let transfer = i2s.write(&buf_a);
        let slot = rx.receive().await;
        buf_b.copy_from_slice(&*slot);
        slot.receive_done();
        transfer.await;

        // Play buf_b, pre-fetch into buf_a
        let transfer = i2s.write(&buf_b);
        let slot = rx.receive().await;
        buf_a.copy_from_slice(&*slot);
        slot.receive_done();
        transfer.await;
    }
}
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

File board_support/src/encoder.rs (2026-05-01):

//! PIO backed quadrature encoder. Stolen from Embassy and reworked for
//! finer-grained counts.

use embassy_rp::{
    Peri,
    gpio::Pull,
    pio::{
        Common, Config, Direction as PioDirection, FifoJoin, Instance, PioPin, ShiftDirection,
        StateMachine, program::pio_file,
    },
    pio_programs::clock_divider::calculate_pio_clock_divider,
};

/// Pio Backed quadrature encoder reader
pub struct Encoder<'d, T: Instance, const SM: usize, const MIN: isize, const MAX: isize> {
    sm: StateMachine<'d, T, SM>,
    pos: isize,
}

impl<'d, T: Instance, const SM: usize, const MIN: isize, const MAX: isize>
    Encoder<'d, T, SM, MIN, MAX>
{
    /// Configure a state machine with the loaded [PioEncoderProgram]
    pub fn new(
        common: &mut Common<'d, T>,
        mut sm: StateMachine<'d, T, SM>,
        pin_a: Peri<'d, impl PioPin>,
        pin_b: Peri<'d, impl PioPin>,
    ) -> Self {
        let prg = pio_file!("src/encoder.s");
        let prg = common.load_program(&prg.program);

        let mut pin_a = common.make_pio_pin(pin_a);
        let mut pin_b = common.make_pio_pin(pin_b);
        pin_a.set_pull(Pull::Up);
        pin_b.set_pull(Pull::Up);
        sm.set_pin_dirs(PioDirection::In, &[&pin_a, &pin_b]);

        let mut cfg = Config::default();
        cfg.set_in_pins(&[&pin_a, &pin_b]);
        cfg.fifo_join = FifoJoin::RxOnly;
        cfg.shift_in.direction = ShiftDirection::Left;

        // Target 12.5 KHz PIO clock
        cfg.clock_divider = calculate_pio_clock_divider(12_500);

        cfg.use_program(&prg, &[]);
        sm.set_config(&cfg);
        sm.set_enable(true);
        Self { sm, pos: MIN }
    }

    /// Read a single count from the encoder. Should be called often enough to
    /// catch updates.
    pub async fn poll(&mut self) -> Direction {
        match self.sm.rx().wait_pull().await {
            // tweaked to match the encoder we have
            0 | 3 => {
                self.pos = MAX.min(self.pos + 1);
                Direction::Clockwise(self.pos)
            }

            1 | 2 => {
                self.pos = MIN.max(self.pos - 1);
                Direction::CounterClockwise(self.pos)
            }

            _ => Direction::NoChange(self.pos),
        }
    }

    pub fn pos(&self) -> isize {
        self.pos
    }

    pub fn min(&self) -> isize {
        MIN
    }

    pub fn max(&self) -> isize {
        MAX
    }
}

/// Encoder Count Direction
pub enum Direction {
    /// Encoder turned clockwise to the given position
    Clockwise(isize),
    /// Encoder turned counterclockwise to the given position
    CounterClockwise(isize),
    /// Encoder did not change position
    NoChange(isize),
}

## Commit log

2026-03-28 feat: first go at TX hardware design
    [tx.kicad_pcb, tx.kicad_sch]
2026-04-07 feat: combined hardware
    [CUI_SJ-3524-SMT-TR.STEP, EC11-THT-15F-green.step, RA-01H--3DModel-STEP-1.STEP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]
2026-04-07 feat: oled model
    [Pantalla OLED 0.96'' 128x64.stp, combined.kicad_pcb]
2026-04-23 feat: support for final board design
    [combined-B_Cu.gbr, combined-B_Mask.gbr, combined-B_Paste.gbr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]
2026-04-29 [broken] switch to master mode on the DAC side
    basically, the bug as far as i can tell was: we were asserting BCK and
    LRCK for the DAC input, but those signals don't stay synchronized with
    the crystal that's driving the DAC's SCK, so every so often (~200 ms
    empirically) the DAC detects a desync, outputs "undefined data" for a
    bit, then resets to 0.5 of full range and starts running again.
    the fix is to use the DAC in master mode, and read BCK/LRCK on the 2350,
    but it's not working yet for unknown reasons.
    [lib.rs, singlecore_loopback.rs]
2026-04-29 [fixed] set DAC to 256 Fs
    no more clicking!
    [lib.rs]
2026-04-29 implement volume control
    this commit:
    - adds an encoder driver (which doesn't use the switch but we can do
    that later)
    - multiplies the incoming audio by that encoder value
    we might want to think a bit harder about more erudite volume control
    mechanisms than "just fkin multiply em" but this certainly works.
    [encoder.rs, lib.rs, singlecore_loopback.rs]
2026-05-01 feat: add output LEDs
2026-05-01 chore: bump output power to 20 dBm
2026-05-02 chore: fixup led
